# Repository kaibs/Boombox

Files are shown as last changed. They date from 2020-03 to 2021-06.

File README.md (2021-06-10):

# WIP! This project still is in an early stage

## 3D printed two-way Boombox

Repository for a fully 3D-printed two-way Bluetooth-speaker.<br/><br/>
<b>REMARK:</b> <i>This is just the documentation of my personal build and in no way a complete instruction to follow along. I provide everything I used to finish this build as an orientation for similar projects</i>

## specifications:
* size: 280x145x125mm (LxWxH)
* fully printed speaker-enclosure
* 2x 2" full range chassis for mids and higher frequencies
* 1x 3" chassis in own subwoofer-compartment for lower frequencies
* digital crossover and equalizer via a ADAU1401 DSP
* digital volume- (rotary encoder) and tone-control (potentiometers)
* APTX Bluetooth connectivity via a CSR64215 which communicates digitally (I<sup>2</sup>S) with the DSP
* 6s Li-Ion battery pack with BMS and USB-C charging (PD 20V) 

## details:

The goal of this project was to design a fully 3D-printable portable Bluetooth-speaker.
The enclosure consists out of 7 parts which can be printed without supports (some screw-holes might be better with) on a 300x300x150mm build-volume. As a material I used simple PLA, although PETG might be a better choice due to its thermal resistance (amplifiers and DC-DCs might get hot).<br/><br/>
The enclosure contains three seperated chambers, one for each speaker-driver. The big subwoofer-compartment in the middle of the casing has a looped horn-like opening and holds a 3" speaker for lower frequencies (50-250Hz). The two side-compartments contain each a 2" full-range chassis for mids and highs.
Each driver currently has its own amplifier (TPA3310, 30W), but replacing two of them with a 2x15W TDA3110 ([like this](https://de.aliexpress.com/item/32969057168.html?spm=a2g0s.9042311.0.0.27424c4dnLOET4)) for the two 2" would probably make more sense.<br/><br/>
The battery of the speaker consists out of six 18650-cells () which are connected in series to a 6s-BMS. The charging happens over an USB-C adapter with a Power-Delivery chip, which delivers an output-voltage of 20V. This way the attaching DC-DC-converter has only to go up by 5.2V, which results in lower heat loss. The downside is that you can only use USB-PD-chargers to power the speaker.<br/><br/>
The "brain" of the speaker is resembled by an ADAU1401 DSP from Analog Devices and a sound-providing CSR64215 Bluetooth-receiver.
The ADAU1401 is a small, self-booting DSP with 4 DACs, so each of the speaker-chassis can have it's own channel. This way, digital audio-processing like EQ, crossovers and other balancing, can happen completely in software. The board also allows using it's GPIOs for manipulating parameters. Volume- and tone-control is realized with rotary-encoders and potentiometers.
The Bluetooth-receiver is connected as a slave via I<sup>2</sup>S to the DSP to avoid any loss in quality due to unnecessary ADC-DAC-conversions.

## drivers and software
* [Drivers for the EZ-USB](https://www.diyaudio.com/forums/digital-line-level/269111-low-cost-usbi-programmer-using-cypress-cy7c68013a-board-post5536992.html) (DSP programmer)
* [Analog Devices Sigma Studio](https://www.analog.com/en/design-center/evaluation-hardware-and-software/software/ss_sigst_02.html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) (DSP dev-tool)

The software necessary for programming the CSR64215 Bluetooth-module (setting name, I<sup>2</sup>S-mode, sampling freq etc.) is a little hard to get. Offically this tools aren't made for the consumer-market and therefore only available for business-clients ([csrsupport.com](http://www.csrsupport.com/)).
However the software is often shared in forums like in [this](http://www.hifi-forum.de/index.php?action=browseT&forum_id=71&thread=12581&back=1&sort=lpost&z=43) thread in the German [hifi-forum.de](http://www.hifi-forum.de/).

## further readings:

* [programming the ADAU1401 with an cheap USBI-TO-EZ-ADAPTER](https://www.meddens.eu/audio/USBi.html)
* [AnalogDevices Sigma Studio documentation](https://wiki.analog.com/resources/tools-software/sigmastudio)
* [Flashing the ADAU1401 in Sigma Studio](https://suredsp.ratz-it.de/index.php?title=Basissetup_erstellen_und_hochladen) (German)
* [Using the CSR64215 with the ADAU1401](https://suredsp.ratz-it.de/index.php?title=CSRA64215) (German)
* [Using GPIOs on the ADAU1401](https://suredsp.ratz-it.de/index.php?title=GPIO_Pins_verwenden) (German)
* [Using potentiometers on the ADAU1401](https://suredsp.ratz-it.de/index.php?title=Potentiometer_verwenden) (German)

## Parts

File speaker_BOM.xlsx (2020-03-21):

component | quantity | price/unit | price | link
ADAU1401 | 1 | 14.04 | 14.04 | https://de.aliexpress.com/item/32807805635.html?spm=a2g0s.9042311.0.0.27424c4dRbgajk
CSR64215 | 1 | 8.29 | 8.29 | https://de.aliexpress.com/item/32716171541.html?spm=a2g0s.9042311.0.0.27424c4dMZrLix
18650 Li-Ion | 6 | 3.90 | 23.40 | https://www.nkon.nl/de/rechargeable/li-ion/18650-size/samsung-icr18650-26j.html
6s BMS | 1 | 2.49 | 2.49 | https://de.aliexpress.com/item/32961715968.html?spm=a2g0s.9042311.0.0.27424c4dMZrLix
USB-C breakout | 1 | 2.27 | 2.27 | https://de.aliexpress.com/item/32438313693.html?spm=a2g0s.9042311.0.0.27424c4dQSnMJV
DC-DC BMS 20V->25.2V | 1 | 1.13 | 1.13 | https://de.aliexpress.com/item/32944756517.html?spm=a2g0s.9042311.0.0.27424c4dhsQTqW
DC-DC DSP25.2V->5V | 1 | 0.50 | 0.50 | https://de.aliexpress.com/item/32787166862.html?spm=a2g0o.cart.0.0.52603c00kXS0HE&mp=1
button power | 1 | 1.20 | 1.20 | https://de.aliexpress.com/item/32844270514.html?spm=a2g0s.9042311.0.0.27424c4d728Csl
button Bluetooth | 1 | 1.20 | 1.20 | https://de.aliexpress.com/item/32813204013.html?spm=a2g0s.9042311.0.0.27424c4drCXOiS
encoder | 1 | 0.35 | 0.35 | https://de.aliexpress.com/item/32830508411.html?spm=a2g0s.9042311.0.0.27424c4dbaa4wW
potentiometer | 3 | 0.40 | 1.20 | https://de.aliexpress.com/item/32862187311.html?spm=a2g0o.cart.0.0.1cd33c00nlBMfL&mp=1
amplifier | 3 | 2.20 | 6.60 | https://de.aliexpress.com/item/32849895525.html?spm=a2g0s.9042311.0.0.27424c4dMZrLix
encoder cap | 1 | 1.20 | 1.20 | https://de.aliexpress.com/item/32874070217.html?spm=a2g0o.cart.0.0.3b3d3c00QMyiK0&mp=1
potentiometer cap | 3 | 0.14 | 0.42 | https://de.aliexpress.com/item/4000108924767.html?spm=a2g0o.cart.0.0.52603c00kXS0HE&mp=1
voltage display | 1 | 1.50 | 1.50 | https://de.aliexpress.com/item/33002747292.html?spm=a2g0o.cart.0.0.1ed83c00XVBs25&mp=1
speaker 2" | 2 | 15.30 | 30.60 | http://www.tb-speaker.com/products/w2-2243s
subwoofer 3" | 1 | 38.00 | 38.00 | http://www.tb-speaker.com/products/w3-1876s
isolated DC-DC 5V->3.3V | 1 | 2.40 | 2.40 | https://de.aliexpress.com/item/32913472005.html?spm=a2g0o.cart.0.0.1ed83c00XVBs25&mp=1
USB-C PD breakout 20V | 1 | 1.76 | 1.76 | https://de.aliexpress.com/item/4000124529027.html?spm=a2g0s.9042311.0.0.71c84c4dz2rsXa
srews
M3 25mm | 8 | 3.78 | 3.78 | https://de.aliexpress.com/item/32404922913.html?spm=a2g0o.cart.0.0.ad673c00RfkemH&mp=1
M3 20mm | 8 | 3.24 | 3.24 | https://de.aliexpress.com/item/32404922913.html?spm=a2g0o.cart.0.0.ad673c00RfkemH&mp=1
M3 6mm threaded insert | 16 | 1.90 | 1.90 | https://de.aliexpress.com/item/32961915881.html?spm=a2g0s.9042311.0.0.27424c4dBlK0pZ
additional parts
programmer CSR | 1 | 12.84 | 12.84 | https://de.aliexpress.com/item/33029998111.html?spm=a2g0s.9042311.0.0.27424c4daNIN52
programmer ADAU | 1 | 2.82 | 2.82 | https://de.aliexpress.com/item/32666671073.html?spm=a2g0s.9042311.0.0.27424c4dRbgajk
filament | ca. 0.5kg
wiring, connectors
 |  | total cost | 163.13

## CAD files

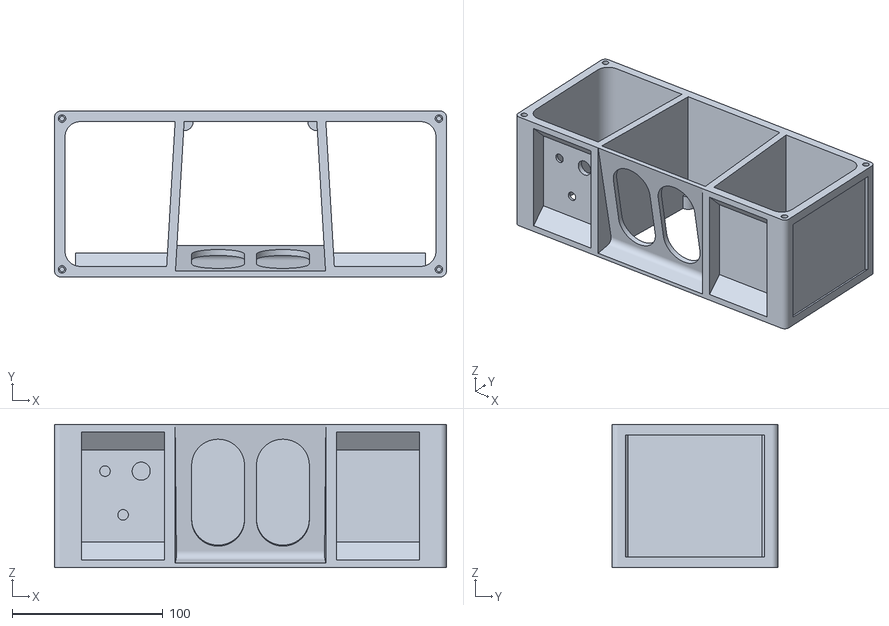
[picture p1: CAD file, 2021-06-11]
cad_v2/stl/main_frame-v2.stl
260.0 x 110.0 x 95.0

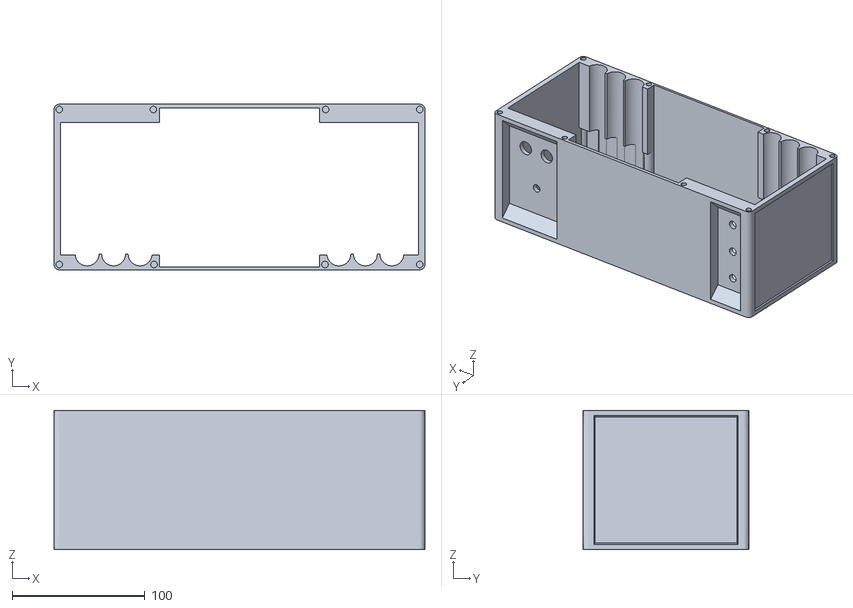
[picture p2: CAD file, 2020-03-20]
3d_files/main_body.stl
280.0 x 125.0 x 105.0

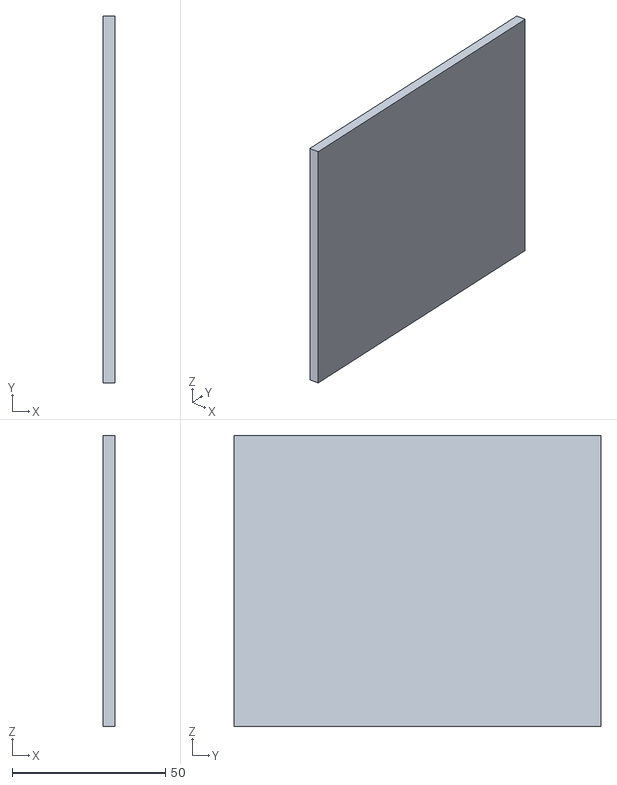
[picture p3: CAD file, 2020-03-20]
3d_files/bass_reflex_p2.stl
3.80 x 119.6 x 95.0

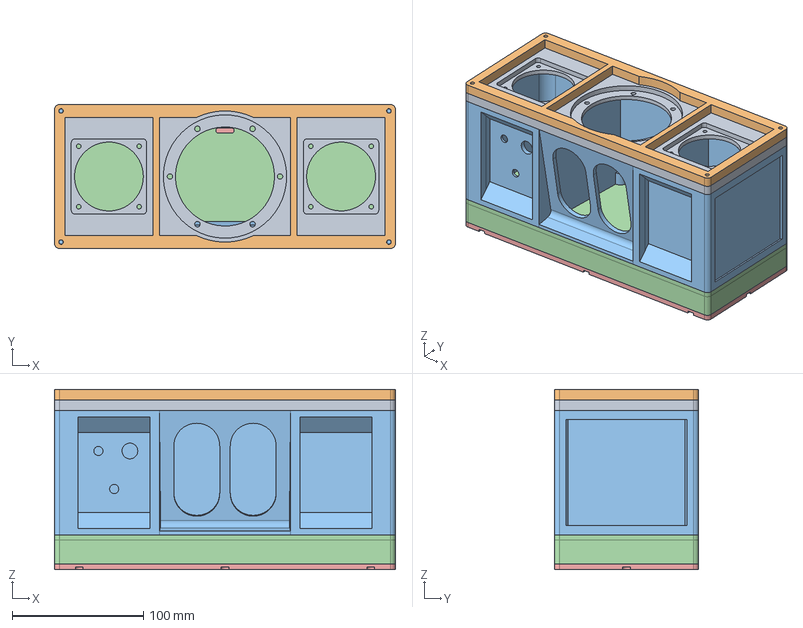
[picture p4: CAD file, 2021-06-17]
cad_v2/boombox_v2.FCStd
260.0 x 110.0 x 137.5 mm
front plate
front frame
main frame
back compartment
back cover

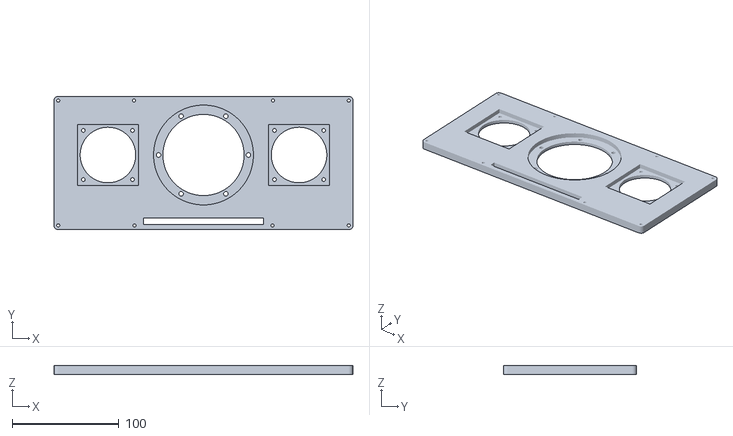
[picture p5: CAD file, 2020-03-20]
3d_files/front_plate.stl
280.0 x 125.0 x 8.00

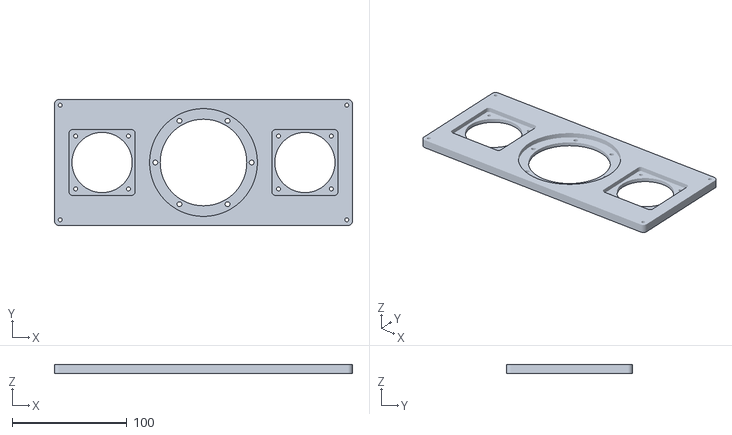
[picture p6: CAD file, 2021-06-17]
cad_v2/stl/front plate_v1.stl
260.0 x 110.0 x 8.00

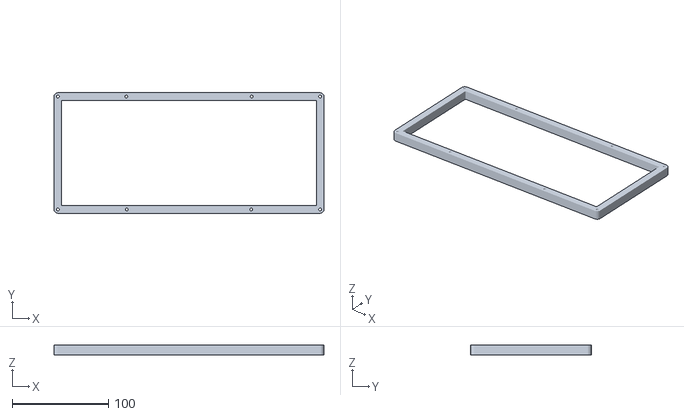
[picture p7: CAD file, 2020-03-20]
3d_files/spacer_ring.stl
280.0 x 125.0 x 10.0

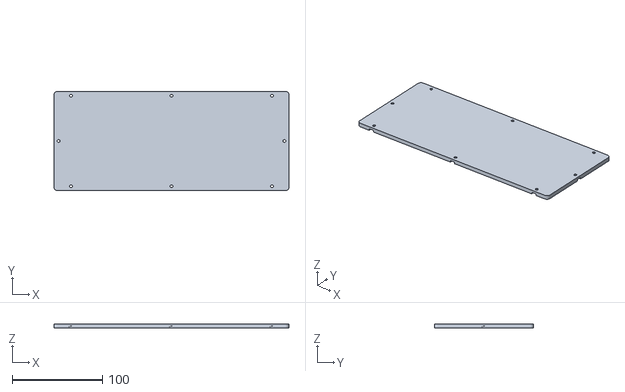
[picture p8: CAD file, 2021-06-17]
cad_v2/stl/back cover_v1.stl
260.0 x 110.0 x 4.50

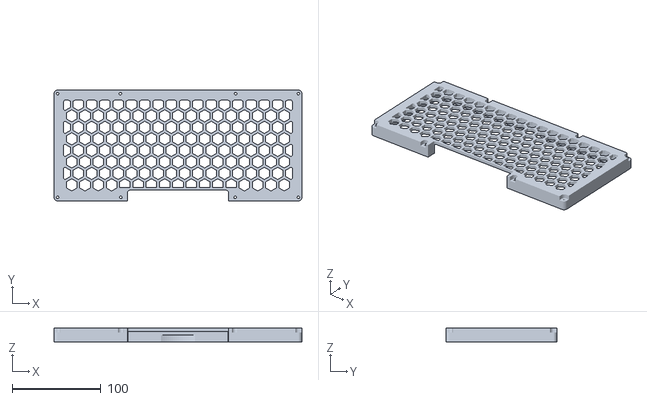
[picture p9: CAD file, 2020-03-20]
3d_files/front_cover.stl
280.0 x 125.0 x 16.0

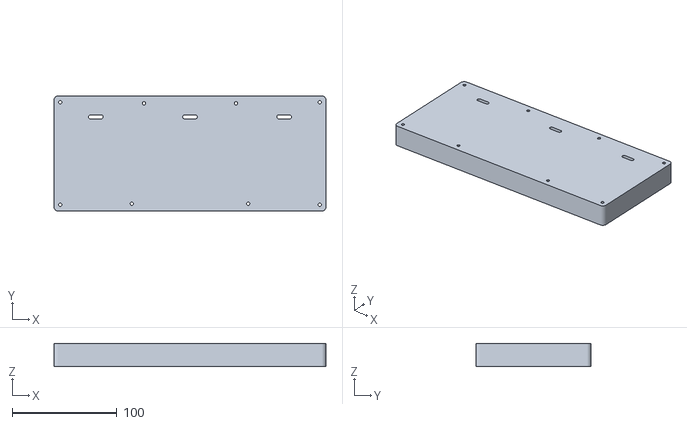
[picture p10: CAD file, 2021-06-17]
cad_v2/stl/back compartment_v2.stl
260.0 x 110.0 x 22.0

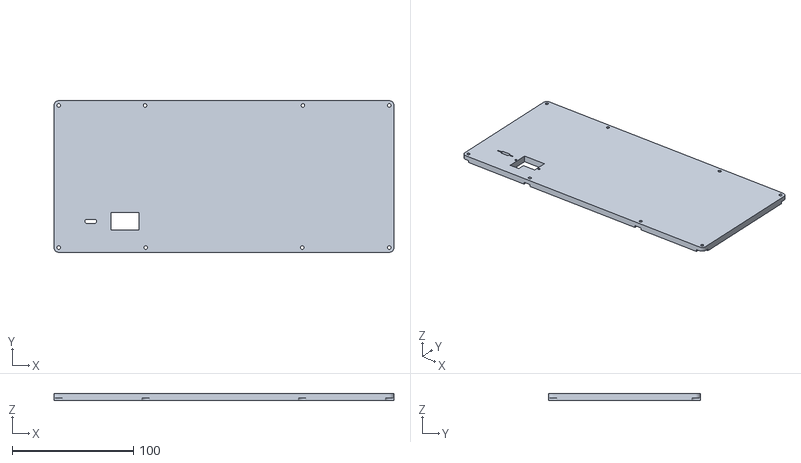
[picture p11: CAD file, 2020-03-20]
3d_files/back_plate.stl
280.0 x 125.0 x 6.00

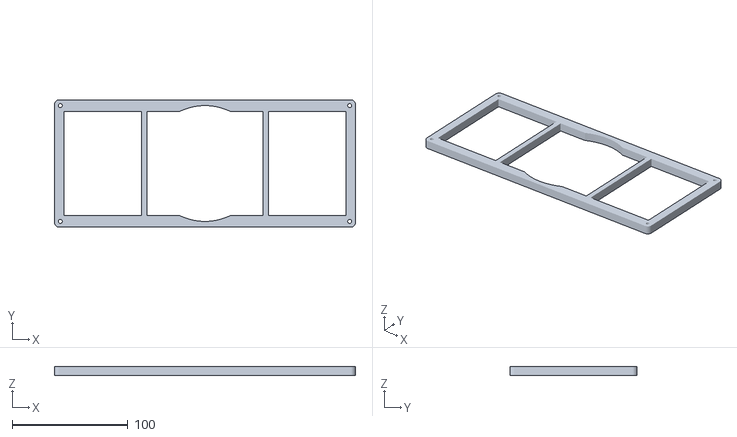
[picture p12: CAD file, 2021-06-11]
cad_v2/stl/front_frame-v2.stl
260.0 x 110.0 x 8.00

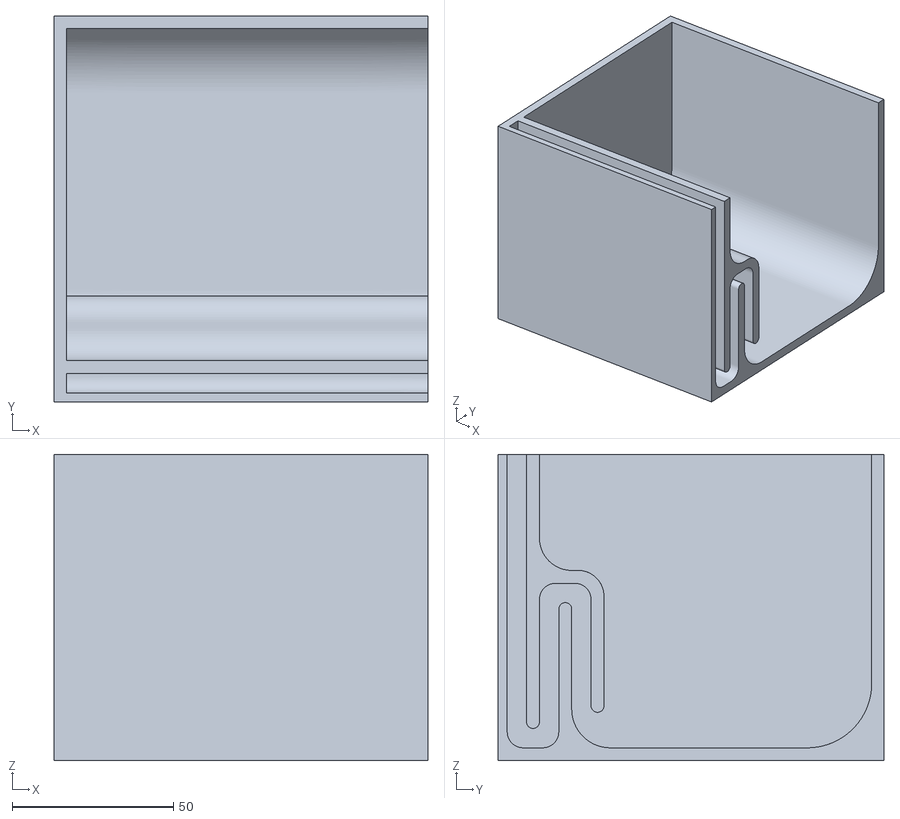
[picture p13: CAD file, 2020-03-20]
3d_files/bass_reflex_p1.stl
115.8 x 119.6 x 95.0

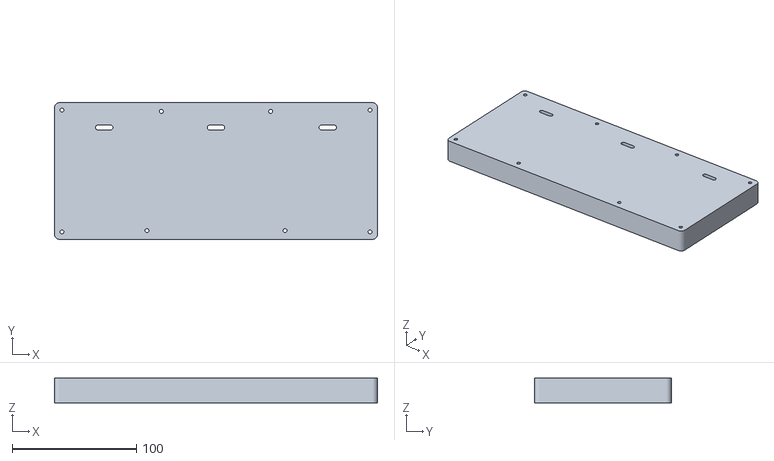
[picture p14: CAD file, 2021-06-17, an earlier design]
cad_v2/stl/back compartment_v1.stl
260.0 x 110.0 x 20.0

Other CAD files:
cad_v2/boombox_v1.FCStd

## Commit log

2020-03-20 added .stl files
    [back_plate.stl, bass_reflex_p1.stl, bass_reflex_p2.stl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]
2020-03-21 added BOM
    [speaker_BOM.xlsx]
2021-06-10 added CAD for v2
    [boombox_v1.FCStd]
2021-06-10 CAD back compartment
    [boombox_v1.FCStd]
2021-06-11 added 260mm version
    [boombox_v2.FCStd, front_frame-v2.stl]
2021-06-11 back cover
    [boombox_v2.FCStd, main_frame-v2.stl]
2021-06-17 STLs, enlarged back compartment
    [back compartment_v1.stl, back compartment_v2.stl, back cover_v1.stl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]
